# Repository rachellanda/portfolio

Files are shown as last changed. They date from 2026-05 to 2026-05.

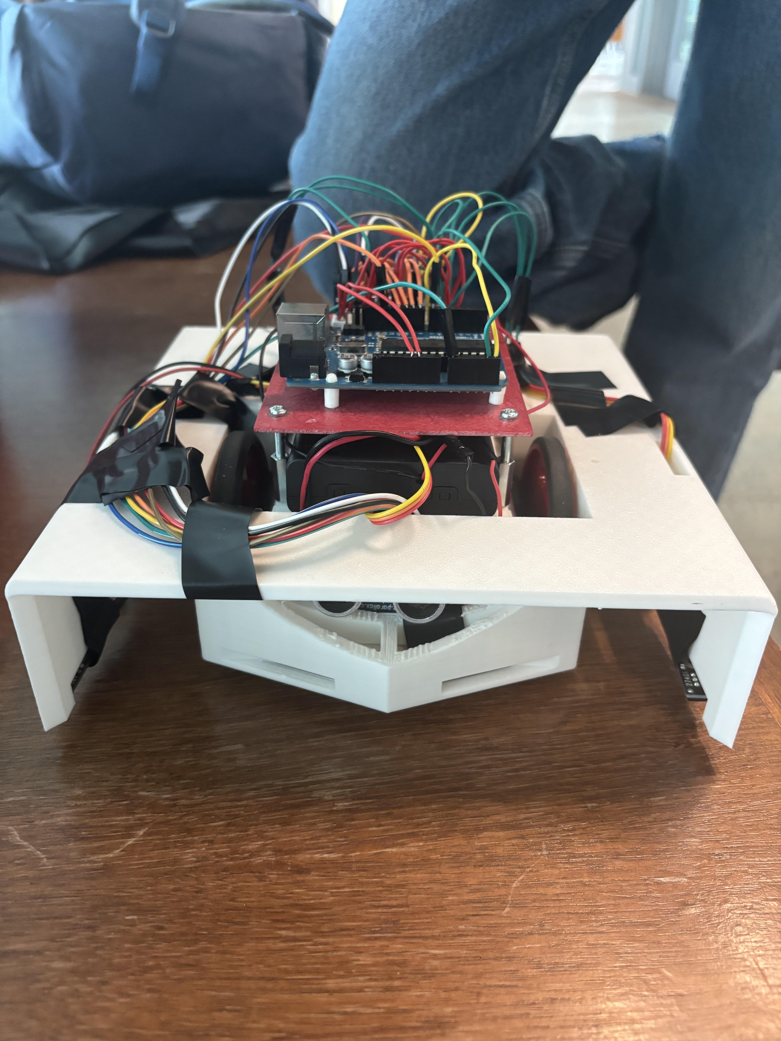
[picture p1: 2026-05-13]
projects/robot-competition/Images/unnamed (3).jpg

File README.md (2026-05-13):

<!DOCTYPE html>
<html>
<head>
  <title>Rachel Landa Portfolio</title>
</head>
<body>
  <h1>Rachel Landa</h1>
  <p>Engineering student interested in robotics and biomedical devices.</p>

  <h2>Projects</h2>

  <h3>Cube Collecting Robot with QTI Border Detection</h3>
  <p>Designed a robot for the MAE 3780 Cube Craze Competition using QTI sensor border detection and continuous rotation servos for driving. This robot is Arduino controlled.</p>

  <h2>Skills</h2>
  <p>C++, Python, Arduino, MATLAB, SolidWorks, Fusion 360</p>

  <h2>Contact</h2>
  <p>Email: rachelslanda@gmail.com</p>
</body>
</html>

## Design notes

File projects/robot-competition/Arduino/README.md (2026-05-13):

# Arduino Code

This folder contains the Arduino code used for the robot project.

## Files Included
- [Final Competition Code](MAE3783RobotFinal.ino)  
  Main Arduino code used during the robot competition.

- [QTI Threshold Test Code](QTIThresholdTest.ino)  
  Test code used to measure and tune the QTI sensor threshold values for detecting the black border.

## Purpose

The Arduino code controls the robot’s driving behavior, sensor readings, and competition strategy. The QTI test code was used during calibration to make sure the sensors could reliably distinguish between the black border and the rest of the board.

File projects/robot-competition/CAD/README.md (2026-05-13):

# CAD Files

This folder contains the CAD files for the robot design.

## Files Included

- [Full Robot Assembly](boe-bot.SLDASM)  
  SolidWorks assembly file showing how the main robot components fit together.

- [Chassis STEP File](Part1%5Eboe-bot.STE)  
  Exported chassis model for easier viewing and sharing across CAD programs.

## Purpose

The CAD files show the physical design of the robot, including the outer shell/chassis used to protect the wheels, guide cubes toward the robot body, and keep the robot low and stable during competition.

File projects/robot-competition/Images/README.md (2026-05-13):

# Images

This folder contains images of the final robot.

## Files Included

- **Final robot photo**: Picture of the completed competition robot.

## Purpose

The image shows the final physical build, including the chassis, sensor placement, and overall robot design.

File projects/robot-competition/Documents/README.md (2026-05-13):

# Documents

This folder contains supporting documentation for the robot project.

## Files Included

- **Wiring diagram**: Shows the electrical connections between the Arduino, sensors, servos, and other robot components.

## Purpose

The wiring diagram documents how the robot hardware was connected and helps make the project easier to understand, rebuild, or troubleshoot.

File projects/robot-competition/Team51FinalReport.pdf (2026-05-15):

# MAE3780 Final Report Team Number: 51 Team Members: [Rachel Landa, rsl85], [Aaron Chin, adc263]

# 1. Robot Design and Strategy Overview

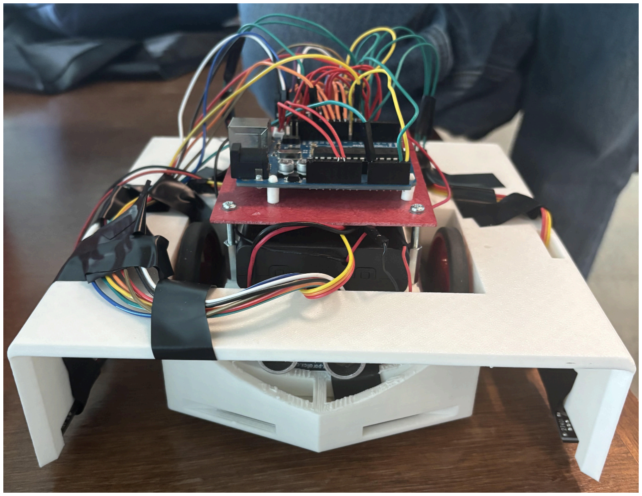
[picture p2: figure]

Our robot was designed for the MAE 3780 robotics competition with a focus on board control and physical dominance. Built on the standard BOE-Bot platform, its primary mechanical feature was an 8 in. × 8 in. outer shell surrounding the chassis (see Appendix C). The shell protected the wheels from cube jamming while creating internal space for passive cube collection. A slanted front edge guided cubes into the side openings as the robot drove forward. The robot was kept low to the ground for stability and pushing effectiveness, with servos mounted inward to maximize internal collection

space.

# The robot used two QTI sensors for black border detection and the standard continuous-rotation servo drives. Ultrasonic and 2 color sensors were wired but unused

in the competition code main to lessen complexity (See Appendix B for wiring diagram).

# The Ultrasonic sensor were disconnected before the competition, so they were only

wired during testing.

# The software strategy was deliberately simple and robust: drive forward after a short

random initial turn, continue until a QTI sensor detected the border, then briefly reverse,

# perform a timed turn, and resume forward motion. The overall behavior leveraged physical reliability over complex sensing or targeting (Appendix D, Appendix E). It limited system errors to reliably sense the playing field edge and resume passive

collection.

# 2. Design Process Reflection

# The design process began by identifying key failure modes: wheel obstruction, weak

pushing power, and driving off the board. This led us to prioritize mechanical protection, a wide, stable footprint, and reliable border detection over active or complex systems.

At first, we chose a passive cube collection using a cardboard structure and one color sensor. We had a difficult time reliably sensing the edge of the playing field with this setup and needed the sensor to be further in front of the robot to sense color accurately before driving off the board. We then swapped to a wide rigid chassis to securely attach sensors ~2in. in front of the drive wheels to ensure we wouldn’t drive off the playing field. This was a major issue we had during milestone 4, and we fixed it accordingly for

the competition.

Another issue we had was COM (center-of-mass) location. In milestone 4, we had an issue with inconsistent turning because of the COM being located too far back on the robot and not enough weight on the drive wheels. During prototyping of the main chassis we had for competition, we made sure to create a wide and flat structure with a

low COM and ensure the COM was very close to the drive wheels for reliable control.

# A large portion of time was spent on testing drive timing. We had to calibrate each servo

with a PWM offset to ensure our robot could drive straight, backwards, and turn reliably.

We tackled some of this issue in milestone 2, but it became more apparent when we wanted the robot to drive across the whole playing board accurately. We were looking to have different drive speeds, but this proved difficult because of a changing offset depending on the desired speed. For example, driving at a fast speed needed a PWM offset of about 28 on one wheel, but at a slow speed we needed an offset of 20. This variability would have taken extensive testing to find correct offsets for each speed, so

we settled for 1 speed for the whole competition.

# One Software development focused on a fast QTI sampling loop (Appendix E, under QTI) with tuned thresholds and timed turns for consistent border avoidance. A major

roadblock was cube retention; cubes often slid out during turns or collisions. Ultimately,

# the design’s greatest strengths were its mechanical simplicity, wheel protection, and strong physical presence, while the main weakness remained the lack of secure cube

trapping.

# 3. Competition Analysis

# Our robot finished the tournament with a 3-3-1 record. It performed well in direct physical interactions due to its low COM design. The robot excelled at pushing

opponents, surviving collisions, and keeping its wheels clear thanks to the outer shell. The large contact area also helped control space on the board.

# The QTI border detection strategy worked reliably in most matches. In competition, it successfully detected the border every time it was supposed to and had no errors. Upon

detecting the edge, the robot typically reversed briefly, turned, and continued driving, staying active without driver intervention. Its simple forward-driving approach ensured it

# was almost always engaged, be that pushing cubes, fighting opponents, or

# repositioning. This strategy worked well, as we would collide with opponents and push

them until the border was detected and the opponent was therefore off the playing field.

The main weakness was cube retention. While cubes easily entered the shell, they frequently slid out during maneuvers or impacts, leading to inconsistent scoring. The lack of active targeting was also a double-edged sword: it reduced complexity and failure points but prevented intentional strategy. Overall, the robot’s mechanical robustness and reliable border avoidance were its greatest strengths on competition

day.

# 4. Conclusions

# The robot proved to be a successful, simple, and durable competitor. Its large protective shell, low chassis, and straightforward QTI-based control loop enabled consistent

performance and a competitive 3-3-1 record, particularly in pushing interactions.

# If we could redo the project under the same constraints, we would add one-way flaps or

flexible hinges to the shell openings to improve cube retention. We would retain the low,

# wide chassis but refine the post-border turning routine for greater consistency across

varying battery and surface conditions.

One other issue we would address in the future is the cost of our 3D printed Chassis.

# This chassis was the main component of our robot, but was severely over budget. We had limited time to fix this before competition because of time constraints. We propose possible solutions for this in Appendix A, some of these being weight reduction or

material change.

Advice for next year’s students: Prioritize reliability and simplicity over complexity. A robot that keeps moving, protects its wheels, and stays on the board will usually outperform more ambitious but fragile designs. Test extensively under realistic conditions with collisions and cubes. Most importantly, focus not only on collecting

cubes but on keeping them inside the robot.

# Appendix A: Bill of Materials

Item | Quantity | Purpose | Cost | Used in Final Robot?
Standard BOE-Bot Kit Components | 1 kit | Base chassis, Arduino/control board, servos, wiring | Provided | Yes
QTI Sensors | 2 | Detect black border | Provided + 1 additional free | Yes
Free components (not in kit) - Wires, standoffs/screws, 100kOhm resistors | N/A | Wiring, assembly, and lift circuitry to create space for batteries. Resistors for QTI | Provided | Yes
Custom PLA Outer Shell/Casing ~237.61g using RPL pricing | 1 | Protect wheels and create cube-collection space | $96.05 | Yes
Fasteners/Tape/Adhesiv e | 1 | Attach shell and components | $6 | No
Extra Color Sensor | 1 | Detect color on corners of robot instead of directly infront | $5 | No
Ultrasonic Sensor | 1 | Opponent detection | Provided | No

# Total costs: $11 + 3D-printed component ($96.05) = $107.05

Our main cost was our 3D printed Chassis which was way over budget. Solutions for reducing total costs to under $40. Aim for outer casing to be ~$30.

1. Equivalent casing, with more cutouts: This design was made under tight time constraints

# and can be simplified to main structural components (columns, cross beams, and supporting beams). The wall thickness was also ⅕ in. which can also be reduced to a still

workable threshold of about ⅛ in which is a reasonable 3mm.

# a. Given the reduction of approx. 5mm to 3mm this is about 40% reduction b. Conceptual cutouts (done quickly and can likely be reduced further) reduced the original 237.61g to 177.39g

c.

# d. Given 40% reduction from wall thickness and 177.39g from just conceptual cutouts, we can show an easily achievable reduction to 106.43g. This correlated

to $43 from RPL pricing.

# e. From quick modifications (eyeballing cuts) we were able to conceptualize a new

chassis that is much more near the budget.

# f. We can deduce a Chassis cost of $30 is very much possible with a reasonable

3mm wall thickness, and well planned beam usage.

# Image of conceptual cutouts to reduce material used

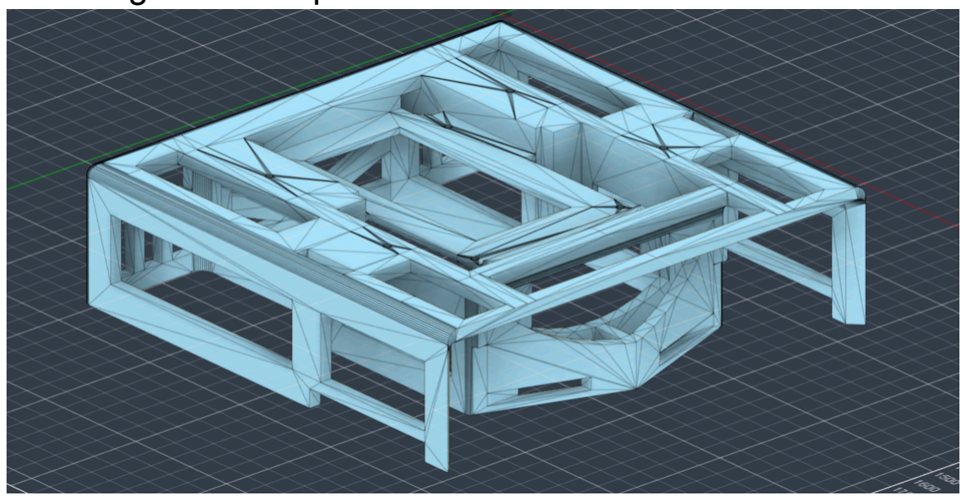
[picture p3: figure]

# 2. Laser cutting + later assembly rather than 3D printing:

a. Laser cutting material is significantly cheaper than 3D printing through the RPL.

b. Since out design is boxy and uses large panels, this is easily translatable to a laser cut design. Laser cut components can be screwed together or even superglued which should hold enough for collisions against other robots 3. Cardboard recreation: a. Because the model is boxy, it can also be recreated with cardboard given large

panels, and cutting out multiple layers for supporting the structure.

# b. Some drawbacks for this method is support cardboard inside the main structure

reduces internal volume to collect cubes.

# c. A better solution would be to combin 3D printed material with super glued cardboard support beams. This can give an okay starting frame that it sturdier can cardboard by itself, but will have more support than just the 3D printed

material with many cutouts.

# Appendix B: Circuit Diagram

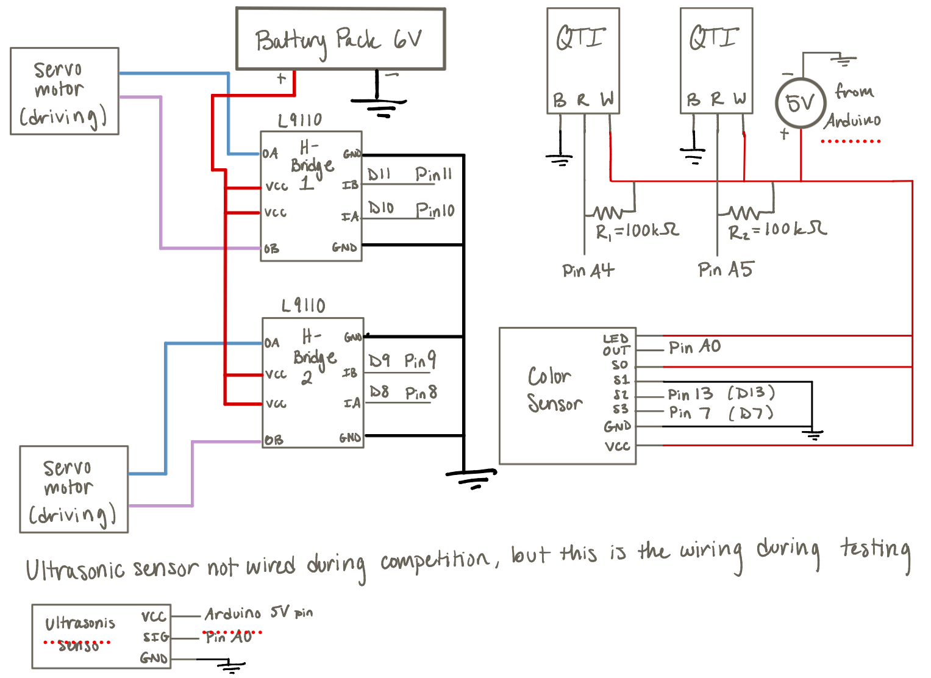
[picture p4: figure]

The final robot used the standard BOE-Bot motor setup with two continuous rotation servos and two QTI sensors for border detection. The QTI sensors and servos were connected as follows:

Component | Signal | Arduino Pin
Left QTI sensor | Analog output A5
Right QTI sensor | Analog output A4
Left motor direction/control | Motor control | D8/D9
Right motor direction/control | Motor control | D10/D11

The Arduino code also included pin definitions for ultrasonic and color sensors, but the final competition loop mainly used the QTI sensors and motor outputs. During competition we kept the color sensor wired, but unplugged the ultrasonic sensor.

# Appendix C: CAD Files and Drawings

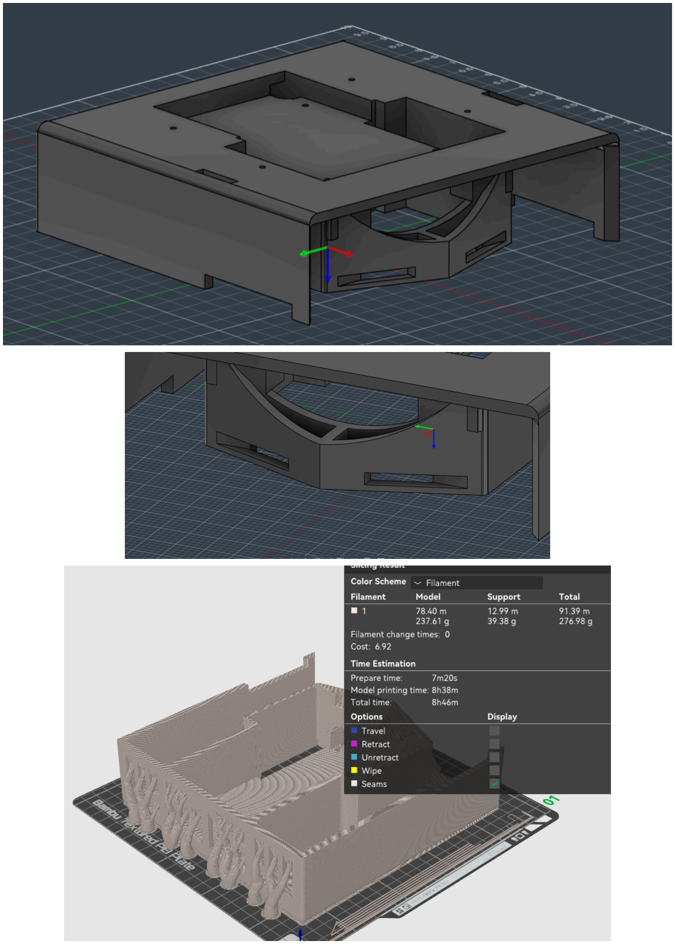
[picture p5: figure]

The most important manufactured part was the large outer shell, approximately 8 in. by 8 in. This shell surrounded the robot and protected the wheels from cube interference. The slanted front guide was designed to redirect cubes toward the side openings of the shell. The servos were positioned closer to the inside of the robot so that the shell could fit around the chassis

# while leaving space for cubes to enter the casing. Weight from BambuLabs: 237.61g

# Appendix D: Flowchart

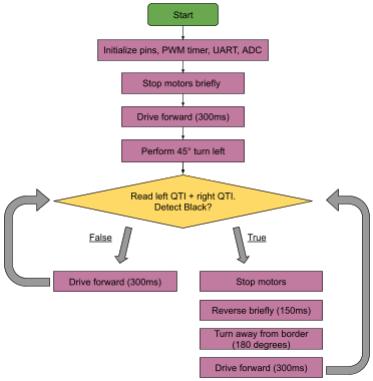
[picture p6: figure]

# This is the flow chart for our strategy logic which we used in our Arduino Code. We follow a simple initialization procedure, then constantly check for the border. When the

border is detected, the robot turns around and continues on. This repeats.

# Appendix E: Code

# The final Arduino code initializes the robot’s pins, PWM outputs, UART communication, ADC

readings, and motor control functions. The final competition loop uses the two QTI sensors to detect the black border. When black is detected, the robot stops, backs up, turns away from the border, and resumes driving forward. The code also includes functions for ultrasonic and color sensing, but these were not central to the final competition behavior.

// Robot w/ QTI sensors, ultrasonic sensor, color sensors, and motor control

// Ultrasonic: D2

// left QTI = A5; right QTI = A4

// left color sensor:

// S2 = D5; S3 = D6; OUT = A1

// right color sensor:

// S2 = D13; S3 = D7; OUT = A0

// Motor driver:

// left DIR = D8; left PWM = D9; right PWM = D10; right DIR = D11

#include <avr/io.h>

// Color IDs

#define COLOR_BLUE 0

#define COLOR_YELLOW 1

#define COLOR_BLACK 2

// Motor speeds

// lower PWM = faster

#define FORWARD_SPEED 24

#define DRIVE_SPEED 200

#define EASE_FAST 40

#define EASE_SLOW 90

#define TURN_SPEED 40

// Turn timing

#define TURN_90_TIME_MS 400

#define TURN_180_TIME_MS 950

// Ultrasonic threshold

#define OBJECT_THRESHOLD_COUNT 2500

// QTI thresholds

#define left_QTI_BLACK_THRESHOLD 1023

#define right_QTI_BLACK_THRESHOLD 400

// Random seed

unsigned long random_state = 12345;

// UART setup

void uart_init() {

UBRR0H = 0;

UBRR0L = 103;

// enable transmitter

UCSR0B = 0b00001000;

// 8-bit data

UCSR0C = 0b00000110;

}

// Send one character

void uart_send_char(char c) {

while (!(UCSR0A & 0b00100000));

UDR0 = c;

}

// Send full string

void uart_send_string(const char* str) {

while (*str != '\0') {

uart_send_char(*str);

str++;

}

}

// Send number through UART

void uart_send_number(long num) {

char buffer[12];

int i = 0;

if (num == 0) {

uart_send_char('0');

return;

}

if (num < 0) {

uart_send_char('-');

num = -num;

}

// store digits backwards

while (num > 0) {

buffer[i] = (num % 10) + '0';

num /= 10;

i++;

}

// print digits in correct order

while (i > 0) {

i--;

uart_send_char(buffer[i]);

}

}

// Approx ms delay

void delay_ms(int ms) {

for (int i = 0; i < ms; i++) {

for (volatile int j = 0; j < 1600; j++) {

__asm__("nop");

}

}

}

// Approx us delay

void delay_us(int us) {

for (int i = 0; i < us; i++) {

for (volatile int j = 0; j < 16; j++) {

__asm__("nop");

}

}

}

// ADC setup

void adc_init() {

// AVcc reference

ADMUX = 0b01000000;

// enable ADC, prescaler 128

ADCSRA = 0b10000111;

}

// Read ADC channel

int adc_read(unsigned char channel) {

// select channel

ADMUX = 0b01000000 | (channel & 0b00001111);

// start conversion

ADCSRA |= 0b01000000;

// wait until done

while (ADCSRA & 0b01000000);

return ADC;

}

// Pin setup

void pins_init() {

// D5,D6,D7 outputs

DDRD = 0b11100000;

// no pullup on D2

PORTD &= 0b11111011;

// motor pins + D13 output

DDRB = 0b00101111;

// PORTC inputs

DDRC = 0b00000000;

}

// PWM setup

void timer1_pwm_init() {

// Fast PWM

TCCR1A = 0b10100001;

TCCR1B = 0b00001011;

// motors stopped

OCR1A = 255;

OCR1B = 255;

}

// Left motor forward

void set_left_motor_forward() {

PORTB |= 0b00000001;

}

// Left motor backward

void set_left_motor_backward() {

PORTB &= 0b11111110;

}

// Right motor forward

void set_right_motor_forward() {

PORTB |= 0b00001000;

}

// Right motor backward

void set_right_motor_backward() {

PORTB &= 0b11110111;

}

// Set motor speeds

void set_motor_speeds(unsigned char left_speed,unsigned char right_speed) {

OCR1A = left_speed;

OCR1B = right_speed;

}

// Move forward

void move_forward() {

set_left_motor_forward();

set_right_motor_forward();

// small correction for drift

set_motor_speeds(FORWARD_SPEED,FORWARD_SPEED + 24);

}

// Move backward

void move_backward() {

set_left_motor_backward();

set_right_motor_backward();

set_motor_speeds(DRIVE_SPEED + 24,DRIVE_SPEED);

}

// Stop motors

void stop_motors() {

set_left_motor_forward();

set_right_motor_forward();

// 255 = stop

set_motor_speeds(255,255);

}

// Turn right ~90 deg

void turn_right_90() {

stop_motors();

delay_ms(100);

set_left_motor_forward();

set_right_motor_backward();

set_motor_speeds(TURN_SPEED,TURN_SPEED);

delay_ms(TURN_90_TIME_MS);

stop_motors();

delay_ms(100);

}

// Turn left ~90 deg

void turn_left_90() {

stop_motors();

delay_ms(100);

set_left_motor_backward();

set_right_motor_forward();

set_motor_speeds(TURN_SPEED,TURN_SPEED);

delay_ms(TURN_90_TIME_MS);

stop_motors();

delay_ms(100);

}

// Turn around

void turn_180() {

stop_motors();

set_left_motor_forward();

set_right_motor_backward();

set_motor_speeds(TURN_SPEED,TURN_SPEED);

delay_ms(TURN_180_TIME_MS);

stop_motors();

}

// Read left QTI

int read_left_qti_raw() {

return adc_read(5);

}

// Read right QTI

int read_right_qti_raw() {

return adc_read(4);

}

// Check if left QTI sees black

int left_qti_black() {

int value = read_left_qti_raw();

if (value >= left_QTI_BLACK_THRESHOLD) {

return 1;

} else {

return 0;

}

}

// Check if right QTI sees black

int right_qti_black() {

int value = read_right_qti_raw();

if (value >= right_QTI_BLACK_THRESHOLD) {

return 1;

} else {

return 0;

}

}

// Print QTI readings

void print_qti_values() {

int left_value = read_left_qti_raw();

int right_value = read_right_qti_raw();

uart_send_string("left QTI A5=");

uart_send_number(left_value);

if (left_value >= left_QTI_BLACK_THRESHOLD) {

uart_send_string(" BLACK");

} else {

uart_send_string(" NOT_BLACK");

}

uart_send_string(" right QTI A4=");

uart_send_number(right_value);

if (right_value >= right_QTI_BLACK_THRESHOLD) {

uart_send_string(" BLACK");

} else {

uart_send_string(" NOT_BLACK");

}

uart_send_string("\r\n");

}

// Ultrasonic pin output

void ultrasonic_pin_output() {

DDRD |= 0b00000100;

}

// Ultrasonic pin input

void ultrasonic_pin_input() {

DDRD &= 0b11111011;

PORTD &= 0b11111011;

}

// Ultrasonic HIGH

void ultrasonic_pin_high() {

PORTD |= 0b00000100;

}

// Ultrasonic LOW

void ultrasonic_pin_low() {

PORTD &= 0b11111011;

}

// Read ultrasonic pin

int read_ultrasonic_pin() {

if (PIND & 0b00000100) {

return 1;

} else {

return 0;

}

}

// Read ultrasonic pulse

long read_ultrasonic_raw() {

long count = 0;

long timeout = 0;

ultrasonic_pin_output();

ultrasonic_pin_low();

delay_us(2);

// trigger pulse

ultrasonic_pin_high();

delay_us(10);

ultrasonic_pin_low();

ultrasonic_pin_input();

// wait for echo

timeout = 0;

while (read_ultrasonic_pin() == 0) {

timeout++;

if (timeout > 30000) {

return -1;

}

}

// measure pulse

count = 0;

while (read_ultrasonic_pin() == 1) {

count++;

if (count > 30000) {

return -2;

}

}

return count;

}

// Check if object detected

int check_object() {

long raw = read_ultrasonic_raw();

if (raw == -1 || raw == -2) {

return 0;

}

// smaller count = closer object

if (raw < OBJECT_THRESHOLD_COUNT) {

return 1;

} else {

return 0;

}

}

// Left sensor RED filter

void left_select_red() {

PORTD &= 0b10011111;

}

// Left sensor GREEN filter

void left_select_green() {

PORTD |= 0b01100000;

}

// Left sensor BLUE filter

void left_select_blue() {

PORTD &= 0b11011111;

PORTD |= 0b01000000;

}

// Right sensor RED filter

void right_select_red() {

PORTB &= 0b11011111;

PORTD &= 0b01111111;

}

// Right sensor GREEN filter

void right_select_green() {

PORTB |= 0b00100000;

PORTD |= 0b10000000;

}

// Right sensor BLUE filter

void right_select_blue() {

PORTB &= 0b11011111;

PORTD |= 0b10000000;

}

// Read left color OUT

int read_left_color_out() {

if (PINC & 0b00000010) {

return 1;

} else {

return 0;

}

}

// Read right color OUT

int read_right_color_out() {

if (PINC & 0b00000001) {

return 1;

} else {

return 0;

}

}

// Read left color pulse

long read_left_color_pulse() {

long count = 0;

long timeout = 0;

while (read_left_color_out() == 1) {

timeout++;

if (timeout > 30000) {

return 30000;

}

}

while (read_left_color_out() == 0) {

count++;

if (count > 30000) {

return 30000;

}

}

return count;

}

// Read right color pulse

long read_right_color_pulse() {

long count = 0;

long timeout = 0;

while (read_right_color_out() == 1) {

timeout++;

if (timeout > 30000) {

return 30000;

}

}

while (read_right_color_out() == 0) {

count++;

if (count > 30000) {

return 30000;

}

}

return count;

}

// Average left color reading

long read_left_color_avg(int samples) {

long total = 0;

for (int i = 0; i < samples; i++) {

total += read_left_color_pulse();

}

return total / samples;

}

// Average right color reading

long read_right_color_avg(int samples) {

long total = 0;

for (int i = 0; i < samples; i++) {

total += read_right_color_pulse();

}

return total / samples;

}

// Read left RGB

void read_left_rgb(long* r,long* g,long* b) {

left_select_red();

delay_ms(10);

*r = read_left_color_avg(1);

left_select_green();

delay_ms(10);

*g = read_left_color_avg(1);

left_select_blue();

delay_ms(10);

*b = read_left_color_avg(1);

}

// Read right RGB

void read_right_rgb(long* r,long* g,long* b) {

right_select_red();

delay_ms(10);

*r = read_right_color_avg(1);

right_select_green();

delay_ms(10);

*g = read_right_color_avg(1);

right_select_blue();

delay_ms(10);

*b = read_right_color_avg(1);

}

// Detect closest color

int detect_color_code(long r,long g,long b) {

long diff_blue = (r - 330)*(r - 330)

+ (g - 180)*(g - 180)

+ (b - 80)*(b - 80);

long diff_yellow = (r - 30)*(r - 30)

+ (g - 50)*(g - 50)

+ (b - 100)*(b - 100);

long diff_black = (r - 550)*(r - 550)

+ (g - 600)*(g - 600)

+ (b - 480)*(b - 480);

if (diff_black <= diff_blue && diff_black <= diff_yellow) {

return COLOR_BLACK;

}

if (diff_blue <= diff_yellow && diff_blue <= diff_black) {

return COLOR_BLUE;

}

return COLOR_YELLOW;

}

// Convert color code to text

const char* color_name(int color_code) {

if (color_code == COLOR_BLACK) {

return "BLACK";

}

if (color_code == COLOR_BLUE) {

return "BLUE";

}

return "YELLOW";

}

// Print RGB + detected colors

void print_color_values_once() {

long left_r,left_g,left_b;

long right_r,right_g,right_b;

read_left_rgb(&left_r,&left_g,&left_b);

read_right_rgb(&right_r,&right_g,&right_b);

int left_color = detect_color_code(left_r,left_g,left_b);

int right_color = detect_color_code(right_r,right_g,right_b);

uart_send_string("left COLOR: ");

uart_send_string(color_name(left_color));

uart_send_string(" R=");

uart_send_number(left_r);

uart_send_string(" G=");

uart_send_number(left_g);

uart_send_string(" B=");

uart_send_number(left_b);

uart_send_string(" right COLOR: ");

uart_send_string(color_name(right_color));

uart_send_string(" R=");

uart_send_number(right_r);

uart_send_string(" G=");

uart_send_number(right_g);

uart_send_string(" B=");

uart_send_number(right_b);

uart_send_string("\r\n");

}

// Simple pseudo random

unsigned long simple_random() {

random_state = random_state * 1103515245 + 12345;

return random_state;

}

// Random movement

void random_small_turn() {

unsigned long r = simple_random() % 3;

if (r == 0) {

turn_left_90();

}

else if (r == 1) {

turn_right_90();

}

else {

move_forward();

delay_ms(150);

}

}

// Handle QTI detection

void handle_qti_event() {

int left_black = left_qti_black();

int right_black = right_qti_black();

if (left_black && right_black) {

uart_send_string("BOTH QTI BLACK: 180\r\n");

turn_180();

random_small_turn();

}

else if (left_black) {

uart_send_string("left QTI BLACK: right 90\r\n");

turn_right_90();

random_small_turn();

}

else if (right_black) {

uart_send_string("right QTI BLACK: left 90\r\n");

turn_left_90();

random_small_turn();

}

}

// Main program

int main() {

pins_init();

timer1_pwm_init();

uart_init();

adc_init();

stop_motors();

delay_ms(100);

uart_send_string("START\r\n");

move_forward();

delay_ms(300);

uart_send_string("INITIAL RANDOM TURN\r\n");

random_small_turn();

// main loop

while (1) {

int left_black = left_qti_black();

int right_black = right_qti_black();

// edge detected

if (left_black || right_black) {

uart_send_string("BLACK DETECTED: TURN 180\r\n");

stop_motors();

delay_ms(100);

move_backward();

delay_ms(150);

turn_180();

move_forward();

delay_ms(300);

}

else {

move_forward();

}

delay_ms(5);

}

return 0;

}

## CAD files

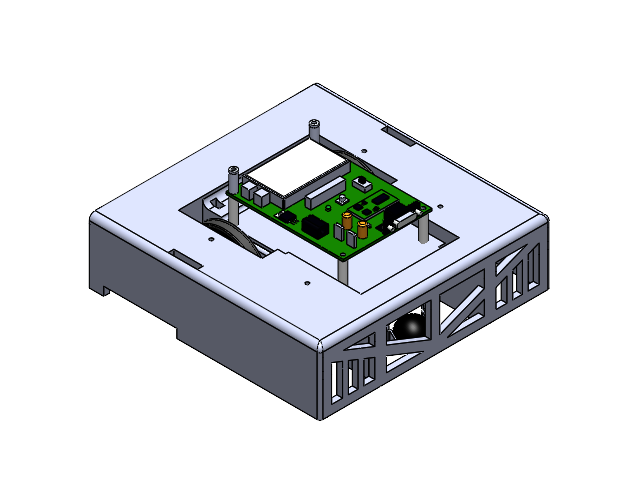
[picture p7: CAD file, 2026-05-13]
projects/robot-competition/CAD/boe-bot.SLDASM
boe-bot
servo motor x 2
odstojnik 25mm x 4
parallax ploåica
caster
felga x 2
guma x 2
kopƒa
odstojnik 15 mm x 2
odstojnik 1,75 mm x 2
Part1^boe-bot

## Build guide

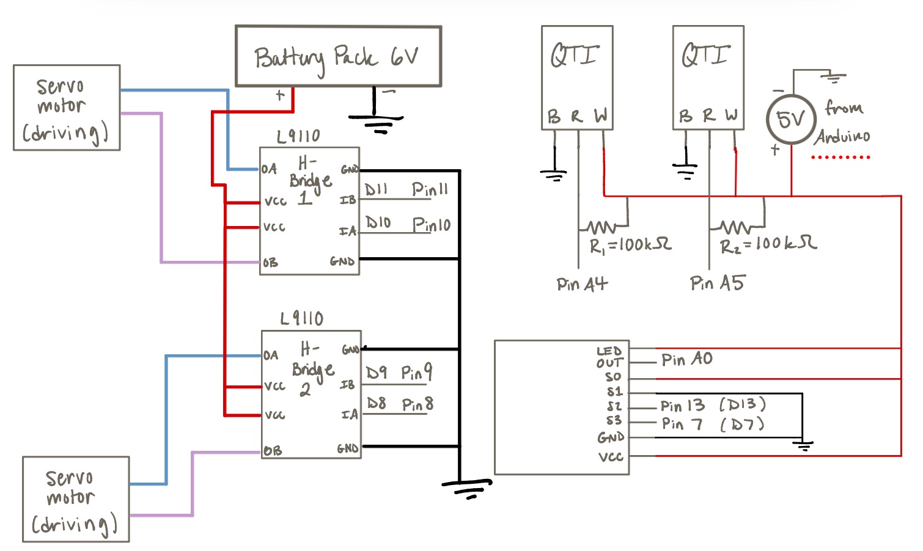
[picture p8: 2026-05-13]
projects/robot-competition/Documents/wiring-diagram.jpeg

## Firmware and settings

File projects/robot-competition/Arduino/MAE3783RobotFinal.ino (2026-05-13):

// Two Analog QTI Sensors + One-Wire Ultrasonic + Two TCS3200 Color Sensors + Robot Movement
// Arduino Uno / ATmega328P
// Register notation only
//
// Ultrasonic:
// SIG = D2
//
// QTI sensors:
// LEFT QTI  = A5
// RIGHT QTI = A4
//
// LEFT color sensor:
// S2  = D5
// S3  = D6
// OUT = A1
//
// RIGHT color sensor:
// S2  = D13
// S3  = D7
// OUT = A0
//
// Motor driver pins:
// LEFT MOTOR DIR  = D8
// LEFT MOTOR PWM  = D9   OC1A
// RIGHT MOTOR PWM = D10  OC1B
// RIGHT MOTOR DIR = D11

#include <avr/io.h>

// ---------------- Color Codes ----------------

#define COLOR_BLUE   0
#define COLOR_YELLOW 1
#define COLOR_BLACK  2

// ---------------- Motor Speeds ----------------
// Your setup is inverted:
// lower PWM number = faster
// 255 = stop

#define FORWARD_SPEED 24
#define DRIVE_SPEED   200
#define EASE_FAST     40
#define EASE_SLOW     90
#define TURN_SPEED    40

#define TURN_90_TIME_MS 400
#define TURN_180_TIME_MS 950

#define OBJECT_THRESHOLD_COUNT 2500

// ---------------- QTI Thresholds ----------------
// Analog ADC range: 0 to 1023
// LEFT QTI = A5
// RIGHT QTI = A4

#define LEFT_QTI_BLACK_THRESHOLD 1023
#define RIGHT_QTI_BLACK_THRESHOLD 400

// ---------------- Random State ----------------

unsigned long random_state = 12345;

// ---------------- UART ----------------

void uart_init() {
    UBRR0H = 0;
    UBRR0L = 103;        // 9600 baud for 16 MHz Arduino Uno
    UCSR0B = 0b00001000; // TXEN0 = 1
    UCSR0C = 0b00000110; // 8-bit data
}

void uart_send_char(char c) {
    while (!(UCSR0A & 0b00100000));
    UDR0 = c;
}

void uart_send_string(const char* str) {
    while (*str != '\0') {
        uart_send_char(*str);
        str++;
    }
}

void uart_send_number(long num) {
    char buffer[12];
    int i = 0;

    if (num == 0) {
        uart_send_char('0');
        return;
    }

    if (num < 0) {
        uart_send_char('-');
        num = -num;
    }

    while (num > 0) {
        buffer[i] = (num % 10) + '0';
        num = num / 10;
        i++;
    }

    while (i > 0) {
        i--;
        uart_send_char(buffer[i]);
    }
}

// ---------------- Delay ----------------

void delay_ms(int ms) {
    for (int i = 0; i < ms; i++) {
        for (volatile int j = 0; j < 1600; j++) {
            __asm__("nop");
        }
    }
}

void delay_us(int us) {
    for (int i = 0; i < us; i++) {
        for (volatile int j = 0; j < 16; j++) {
            __asm__("nop");
        }
    }
}

// ---------------- ADC ----------------

void adc_init() {
    // AVcc reference, ADC right adjusted
    ADMUX = 0b01000000;

    // Enable ADC, prescaler = 128
    ADCSRA = 0b10000111;
}

int adc_read(unsigned char channel) {
    // Select ADC channel, keep AVcc reference
    ADMUX = 0b01000000 | (channel & 0b00001111);

    // Start conversion
    ADCSRA |= 0b01000000;

    // Wait for conversion to finish
    while (ADCSRA & 0b01000000);

    return ADC;
}

// ---------------- Pin + Timer Setup ----------------

void pins_init() {
    // PORTD:
    // D2 = PD2 = ultrasonic SIG, input/output dynamically
    // D5 = PD5 = LEFT color S2 output
    // D6 = PD6 = LEFT color S3 output
    // D7 = PD7 = RIGHT color S3 output
    DDRD = 0b11100000;

    // Pullup OFF for D2
    PORTD &= 0b11111011;

    // PORTB:
    // D8  = PB0 = LEFT MOTOR DIR output
    // D9  = PB1 = LEFT MOTOR PWM output OC1A
    // D10 = PB2 = RIGHT MOTOR PWM output OC1B
    // D11 = PB3 = RIGHT MOTOR DIR output
    // D13 = PB5 = RIGHT color S2 output
    DDRB = 0b00101111;

    // PORTC:
    // A0 = PC0 = RIGHT color OUT input
    // A1 = PC1 = LEFT color OUT input
    // A4 = PC4 = RIGHT QTI analog input
    // A5 = PC5 = LEFT QTI analog input
    DDRC = 0b00000000;
}

void timer1_pwm_init() {
    // Timer1 controls PWM on D9 = OC1A and D10 = OC1B
    TCCR1A = 0b10100001; // Fast PWM 8-bit, non-inverting
    TCCR1B = 0b00001011; // Prescaler = 64

    OCR1A = 255;
    OCR1B = 255;
}

// ---------------- Motor Control ----------------

void set_left_motor_forward() {
    PORTB |= 0b00000001; // D8 HIGH
}

void set_left_motor_backward() {
    PORTB &= 0b11111110; // D8 LOW
}

void set_right_motor_forward() {
    PORTB |= 0b00001000; // D11 HIGH
}

void set_right_motor_backward() {
    PORTB &= 0b11110111; // D11 LOW
}

void set_motor_speeds(unsigned char left_speed, unsigned char right_speed) {
    OCR1A = left_speed;   // D9
    OCR1B = right_speed;  // D10
}

void move_forward() {
    set_left_motor_forward();
    set_right_motor_forward();

    // Right motor slowed slightly so robot drives straight.
    set_motor_speeds(FORWARD_SPEED, FORWARD_SPEED + 24);
}

void move_backward() {
    set_left_motor_backward();
    set_right_motor_backward();

    // Tuned reverse correction
    set_motor_speeds(DRIVE_SPEED + 24, DRIVE_SPEED);
}

void stop_motors() {
    set_left_motor_forward();
    set_right_motor_forward();
    set_motor_speeds(255, 255);
}

void turn_right_90() {
    stop_motors();
    delay_ms(100);

    set_left_motor_forward();
    set_right_motor_backward();
    set_motor_speeds(TURN_SPEED, TURN_SPEED);

    delay_ms(TURN_90_TIME_MS);

    stop_motors();
    delay_ms(100);
}

void turn_left_90() {
    stop_motors();
    delay_ms(100);

    set_left_motor_backward();
    set_right_motor_forward();
    set_motor_speeds(TURN_SPEED, TURN_SPEED);

    delay_ms(TURN_90_TIME_MS);

    stop_motors();
    delay_ms(100);
}

void turn_180() {
    stop_motors();


    set_left_motor_forward();
    set_right_motor_backward();
    set_motor_speeds(TURN_SPEED, TURN_SPEED);

    delay_ms(TURN_180_TIME_MS);

    stop_motors();

}

// ---------------- Analog QTI Reading ----------------

int read_left_qti_raw() {
    // LEFT QTI = A5 = ADC5
    return adc_read(5);
}

int read_right_qti_raw() {
    // RIGHT QTI = A4 = ADC4
    return adc_read(4);
}

int left_qti_black() {
    int value = read_left_qti_raw();

    if (value >= LEFT_QTI_BLACK_THRESHOLD) {
        return 1;
    } else {
        return 0;
    }
}

int right_qti_black() {
    int value = read_right_qti_raw();

    if (value >= RIGHT_QTI_BLACK_THRESHOLD) {
        return 1;
    } else {
        return 0;
    }
}

void print_qti_values() {
    int left_value = read_left_qti_raw();
    int right_value = read_right_qti_raw();

    uart_send_string("LEFT QTI A5=");
    uart_send_number(left_value);

    if (left_value >= LEFT_QTI_BLACK_THRESHOLD) {
        uart_send_string(" BLACK");
    } else {
        uart_send_string(" NOT_BLACK");
    }

    uart_send_string("    RIGHT QTI A4=");
    uart_send_number(right_value);

    if (right_value >= RIGHT_QTI_BLACK_THRESHOLD) {
        uart_send_string(" BLACK");
    } else {
        uart_send_string(" NOT_BLACK");
    }

    uart_send_string("\r\n");
}

// ---------------- One-Wire Ultrasonic Helpers ----------------

void ultrasonic_pin_output() {
    DDRD |= 0b00000100; // D2 output
}

void ultrasonic_pin_input() {
    DDRD &= 0b11111011;  // D2 input
    PORTD &= 0b11111011; // pullup off
}

void ultrasonic_pin_high() {
    PORTD |= 0b00000100;
}

void ultrasonic_pin_low() {
    PORTD &= 0b11111011;
}

int read_ultrasonic_pin() {
    if (PIND & 0b00000100) {
        return 1;
    } else {
        return 0;
    }
}

long read_ultrasonic_raw() {
    long count = 0;
    long timeout = 0;

    ultrasonic_pin_output();

    ultrasonic_pin_low();
    delay_us(2);

    ultrasonic_pin_high();
    delay_us(10);

    ultrasonic_pin_low();

    ultrasonic_pin_input();

    timeout = 0;
    while (read_ultrasonic_pin() == 0) {
        timeout++;

        if (timeout > 30000) {
            return -1;
        }
    }

    count = 0;
    while (read_ultrasonic_pin() == 1) {
        count++;

        if (count > 30000) {
            return -2;
        }
    }

    return count;
}

int check_object() {
    long raw = read_ultrasonic_raw();

    if (raw == -1 || raw == -2) {
        return 0;
    }

    if (raw < OBJECT_THRESHOLD_COUNT) {
        return 1;
    } else {
        return 0;
    }
}

// ---------------- LEFT Color Sensor Filter Selection ----------------
// Color code is included but not used in main right now.

void left_select_red() {
    // LEFT S2 = D5 LOW
    // LEFT S3 = D6 LOW
    PORTD &= 0b10011111;
}

void left_select_green() {
    // LEFT S2 = D5 HIGH
    // LEFT S3 = D6 HIGH
    PORTD |= 0b01100000;
}

void left_select_blue() {
    // LEFT S2 = D5 LOW
    // LEFT S3 = D6 HIGH
    PORTD &= 0b11011111;
    PORTD |= 0b01000000;
}

// ---------------- RIGHT Color Sensor Filter Selection ----------------
// Color code is included but not used in main right now.

void right_select_red() {
    // RIGHT S2 = D13/PB5 LOW
    // RIGHT S3 = D7 LOW
    PORTB &= 0b11011111;
    PORTD &= 0b01111111;
}

void right_select_green() {
    // RIGHT S2 = D13/PB5 HIGH
    // RIGHT S3 = D7 HIGH
    PORTB |= 0b00100000;
    PORTD |= 0b10000000;
}

void right_select_blue() {
    // RIGHT S2 = D13/PB5 LOW
    // RIGHT S3 = D7 HIGH
    PORTB &= 0b11011111;
    PORTD |= 0b10000000;
}

// ---------------- Color Sensor Output Reading ----------------

int read_left_color_out() {
    // LEFT OUT = A1 = PC1
    if (PINC & 0b00000010) {
        return 1;
    } else {
        return 0;
    }
}

int read_right_color_out() {
    // RIGHT OUT = A0 = PC0
    if (PINC & 0b00000001) {
        return 1;
    } else {
        return 0;
    }
}

long read_left_color_pulse() {
    long count = 0;
    long timeout = 0;

    while (read_left_color_out() == 1) {
        timeout++;
        if (timeout > 30000) {
            return 30000;
        }
    }

    while (read_left_color_out() == 0) {
        count++;
        if (count > 30000) {
            return 30000;
        }
    }

    return count;
}

long read_right_color_pulse() {
    long count = 0;
    long timeout = 0;

    while (read_right_color_out() == 1) {
        timeout++;
        if (timeout > 30000) {
            return 30000;
        }
    }

    while (read_right_color_out() == 0) {
        count++;
        if (count > 30000) {
            return 30000;
        }
    }

    return count;
}

long read_left_color_avg(int samples) {
    long total = 0;

    for (int i = 0; i < samples; i++) {
        total += read_left_color_pulse();
    }

    return total / samples;
}

long read_right_color_avg(int samples) {
    long total = 0;

    for (int i = 0; i < samples; i++) {
        total += read_right_color_pulse();
    }

    return total / samples;
}

void read_left_rgb(long* r, long* g, long* b) {
    left_select_red();
    delay_ms(10);
    *r = read_left_color_avg(1);

    left_select_green();
    delay_ms(10);
    *g = read_left_color_avg(1);

    left_select_blue();
    delay_ms(10);
    *b = read_left_color_avg(1);
}

void read_right_rgb(long* r, long* g, long* b) {
    right_select_red();
    delay_ms(10);
    *r = read_right_color_avg(1);

    right_select_green();
    delay_ms(10);
    *g = read_right_color_avg(1);

    right_select_blue();
    delay_ms(10);
    *b = read_right_color_avg(1);
}

int detect_color_code(long r, long g, long b) {
    long diff_blue = (r - 330) * (r - 330)
                   + (g - 180) * (g - 180)
                   + (b - 80)  * (b - 80);

    long diff_yellow = (r - 30) * (r - 30)
                     + (g - 50) * (g - 50)
                     + (b - 100) * (b - 100);

    long diff_black = (r - 550) * (r - 550)
                    + (g - 600) * (g - 600)
                    + (b - 480) * (b - 480);

    if (diff_black <= diff_blue && diff_black <= diff_yellow) {
        return COLOR_BLACK;
    }

    if (diff_blue <= diff_yellow && diff_blue <= diff_black) {
        return COLOR_BLUE;
    }

    return COLOR_YELLOW;
}

const char* color_name(int color_code) {
    if (color_code == COLOR_BLACK) {
        return "BLACK";
    }

    if (color_code == COLOR_BLUE) {
        return "BLUE";
    }

    return "YELLOW";
}

void print_color_values_once() {
    long left_r;
    long left_g;
    long left_b;

    long right_r;
    long right_g;
    long right_b;

    read_left_rgb(&left_r, &left_g, &left_b);
    read_right_rgb(&right_r, &right_g, &right_b);

    int left_color = detect_color_code(left_r, left_g, left_b);
    int right_color = detect_color_code(right_r, right_g, right_b);

    uart_send_string("LEFT COLOR: ");
    uart_send_string(color_name(left_color));
    uart_send_string(" R=");
    uart_send_number(left_r);
    uart_send_string(" G=");
    uart_send_number(left_g);
    uart_send_string(" B=");
    uart_send_number(left_b);

    uart_send_string("     RIGHT COLOR: ");
    uart_send_string(color_name(right_color));
    uart_send_string(" R=");
    uart_send_number(right_r);
    uart_send_string(" G=");
    uart_send_number(right_g);
    uart_send_string(" B=");
    uart_send_number(right_b);

    uart_send_string("\r\n");
}

// ---------------- Random Direction ----------------

unsigned long simple_random() {
    random_state = random_state * 1103515245 + 12345;
    return random_state;
}

void random_small_turn() {
    unsigned long r = simple_random() % 3;

    if (r == 0) {
        turn_left_90();
    }
    else if (r == 1) {
        turn_right_90();
    }
    else {
        move_forward();
        delay_ms(150);
    }
}

// ---------------- Fast QTI Competition Logic ----------------

void handle_qti_event() {
    int left_black = left_qti_black();
    int right_black = right_qti_black();

    if (left_black && right_black) {
        uart_send_string("BOTH QTI BLACK: 180\r\n");
        turn_180();
        random_small_turn();
    }
    else if (left_black) {
        uart_send_string("LEFT QTI BLACK: RIGHT 90\r\n");
        turn_right_90();
        random_small_turn();
    }
    else if (right_black) {
        uart_send_string("RIGHT QTI BLACK: LEFT 90\r\n");
        turn_left_90();
        random_small_turn();
    }
}

// ---------------- Main ----------------

int main() {
    pins_init();
    timer1_pwm_init();
    uart_init();
    adc_init();

    stop_motors();
    delay_ms(100);

    uart_send_string("START\r\n");

    // Start going straight
    move_forward();
    delay_ms(300);

    // Choose random turn ONLY ONCE at the beginning
    uart_send_string("INITIAL RANDOM TURN\r\n");
    random_small_turn();

    // Then only drive straight until black, turn 180, repeat
    while (1) {
        int left_black = left_qti_black();
        int right_black = right_qti_black();

        if (left_black || right_black) {
            uart_send_string("BLACK DETECTED: TURN 180\r\n");

            stop_motors();
            delay_ms(100);

            move_backward();
            delay_ms(150);


            turn_180();

            // Drive forward after turning away from black
            move_forward();
            delay_ms(300);
        }
        else {
            move_forward();
        }

        // Fast QTI sampling
        delay_ms(5);
    }

    return 0;
}
